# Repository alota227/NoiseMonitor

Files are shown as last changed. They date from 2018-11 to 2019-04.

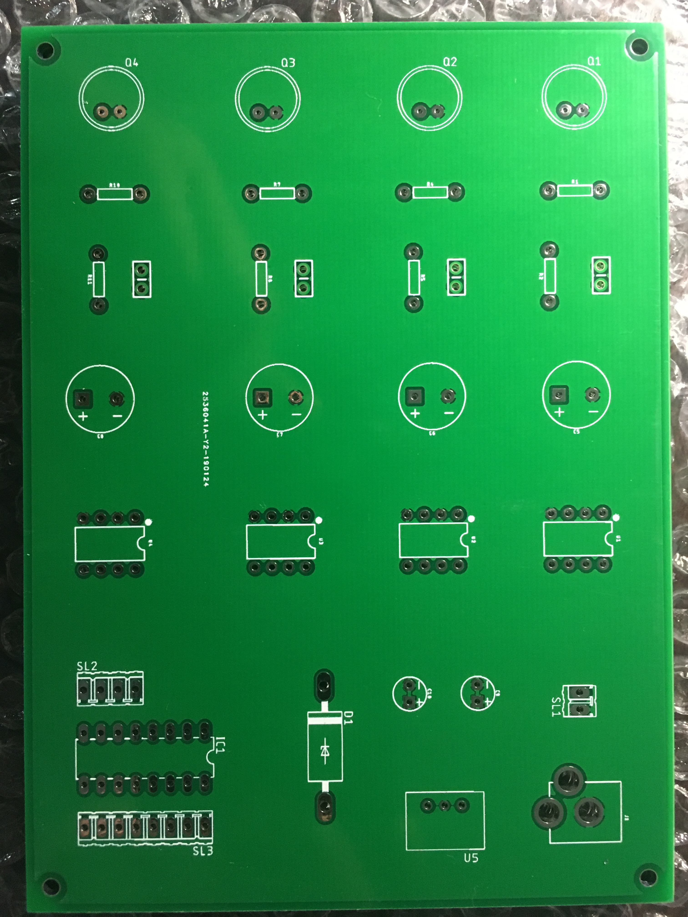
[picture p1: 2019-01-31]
PCB_Design_Eagle/IMG_4661.JPG

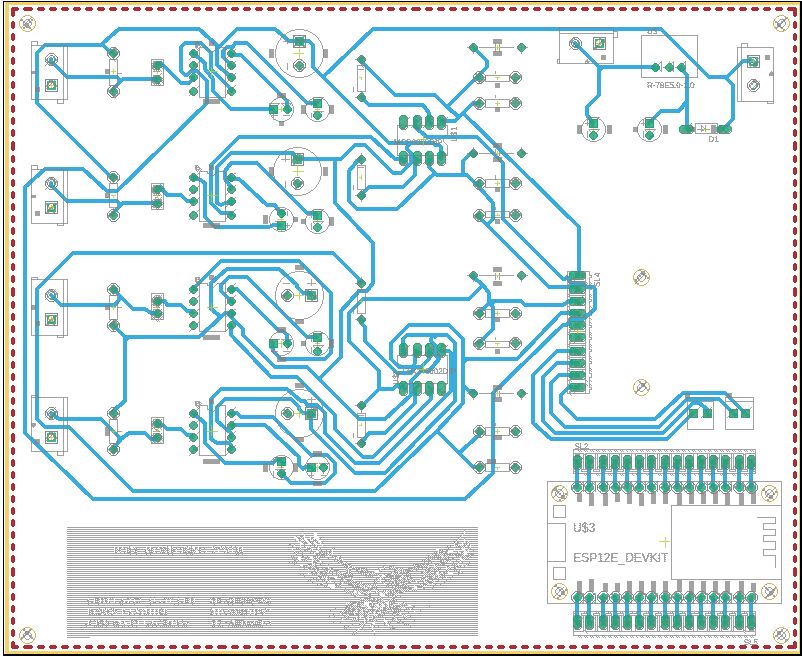
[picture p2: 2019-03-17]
PCB_Design_Eagle/Mic_PCB_Layout.JPG

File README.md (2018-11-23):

# NoiseMonitor
To design a  noise monitoring system that is able to detect and localize the noise levels in an area and analyze the data obtained through the cloud. The system will have several (2-3) nodes that can communicate with each other to analyze the data accurately. The data will be classified through an auto-map system that can identify the low/high level noise areas in real-time. The device is a solution that can solve the issues and concerns of noise pollution in Saskatchewan.

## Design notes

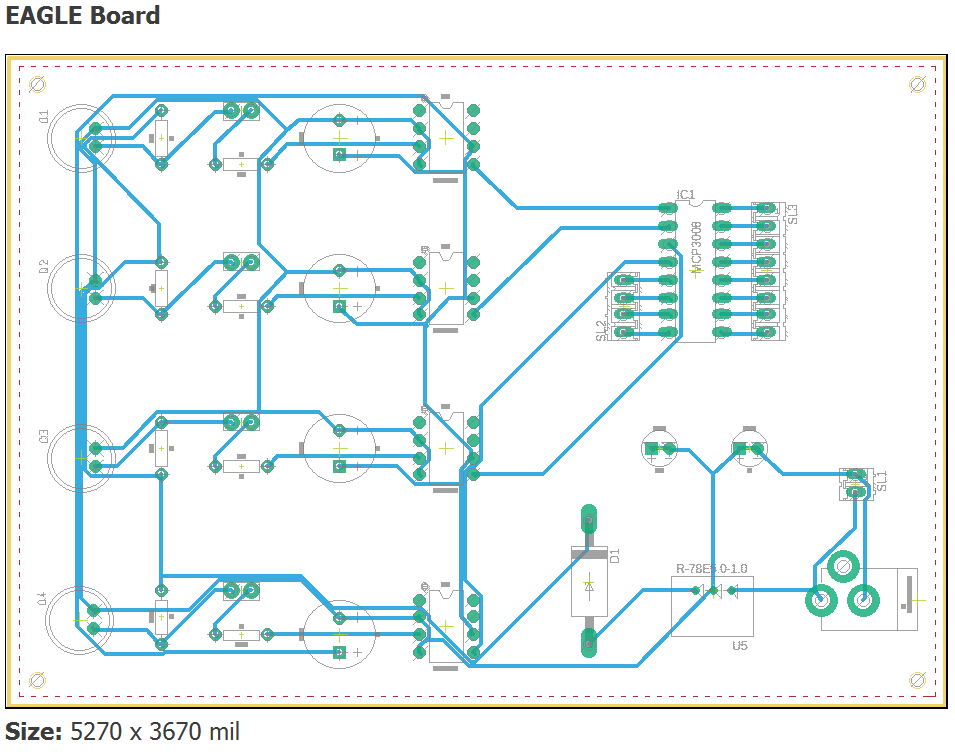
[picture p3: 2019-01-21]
PCB_Design_Eagle/node1_board_v2.PNG

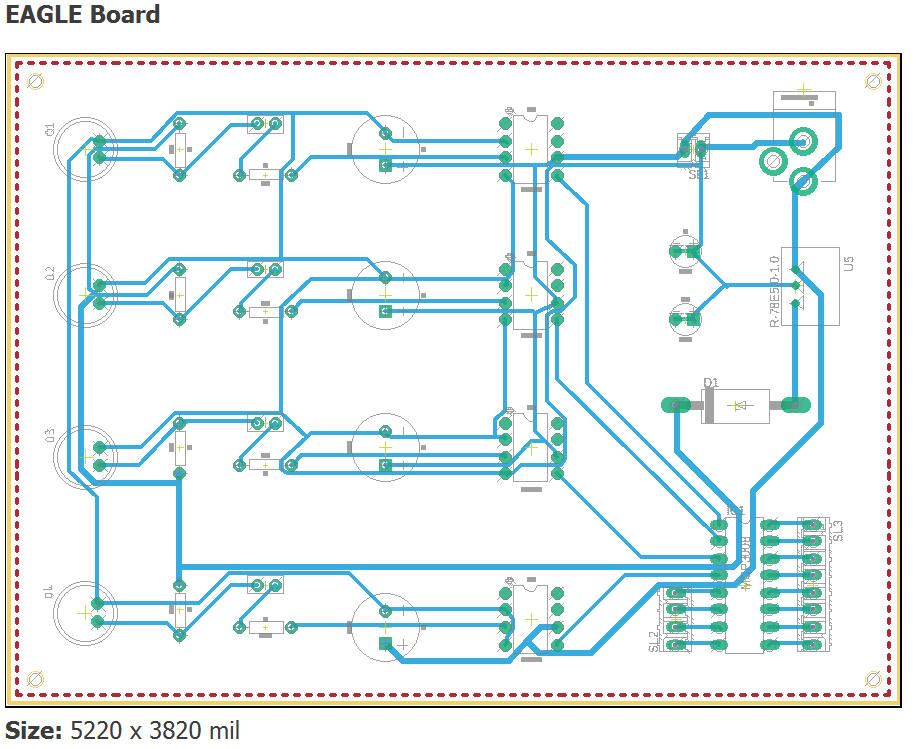
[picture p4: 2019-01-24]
PCB_Design_Eagle/node1_board_v33.PNG

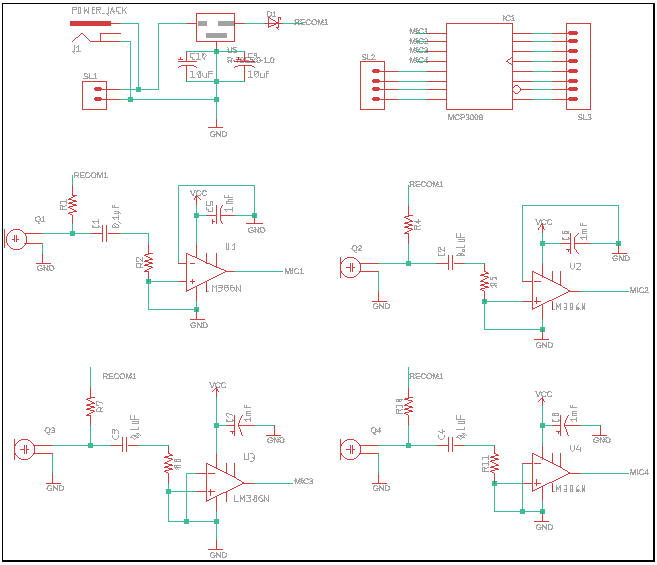
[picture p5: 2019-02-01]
PCB_Design_Eagle/Schematic.PNG

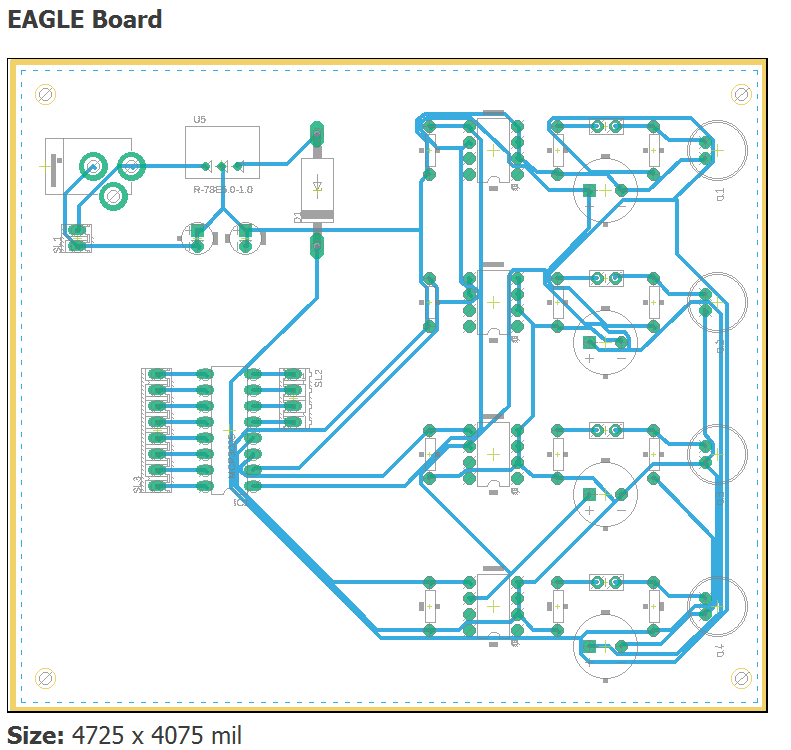
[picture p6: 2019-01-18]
PCB_Design_Eagle/node1_board_v1.PNG

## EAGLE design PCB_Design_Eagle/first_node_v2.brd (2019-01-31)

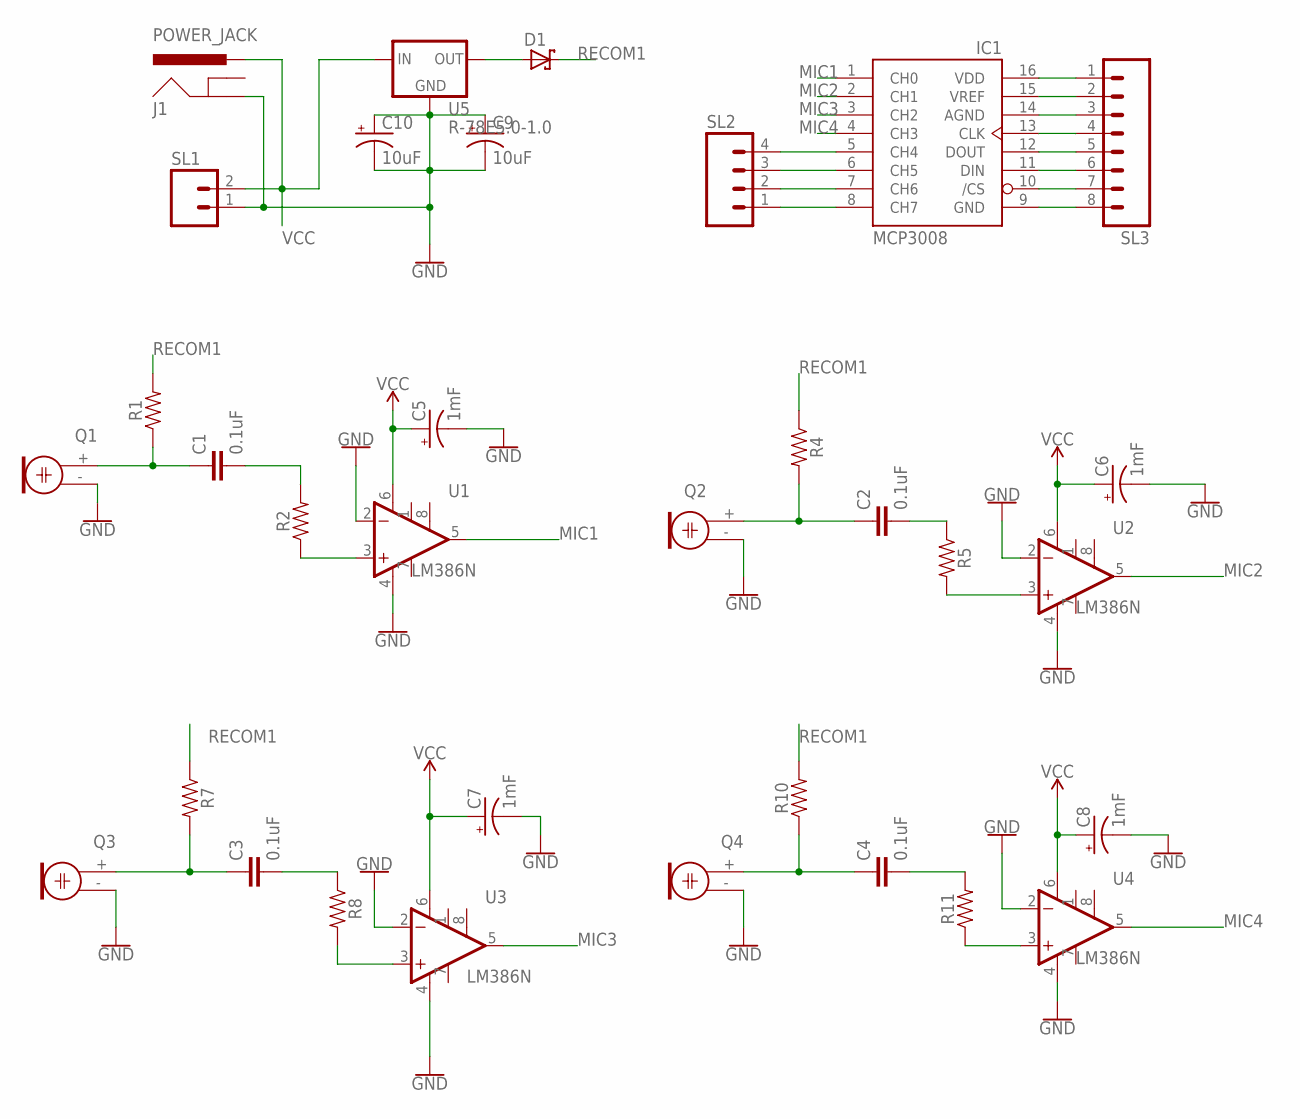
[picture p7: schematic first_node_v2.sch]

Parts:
C1, C2, C3, C4: 0.1uF; CAP-PTH-SMALL-KIT
C5, C6, C7, C8: 1mF; CPOL-RADIAL-5MM-10MM
C9, C10: 10uF; CPOL-RADIAL-2.5MM-5MM
D1: SCHOTTKY-DIODECB429-17; CB429-17
IC1: MCP3008; DIL16
J1: POWER_JACK; POWER_JACK_PTH
Q1, Q2, Q3, Q4: ELECTRET; 9.7ELECTRET
R1, R2, R4, R5, R7, R8, R10, R11: AXIAL-0.3
SL1: M02; 02P
SL2: M04; 04P
SL3: M08; 08P
U1, U2, U3, U4: LM386N; DIP08
U5: R-78E5.0-1.0; DC-DC_CONVERTER_78XX

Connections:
GND: C5.-, C6.-, C7.-, C8.-, C9.1 (+), C9.2 (-), C10.1 (+), C10.2 (-), J1.GND, Q1.- (1), Q2.- (1), Q3.- (1), Q4.- (1), SL1.1, U1.2 (-IN), U1.4 (V-), U2.2 (-IN), U2.4 (V-), U3.2 (-IN), U3.4 (V-), U4.2 (-IN), U4.4 (V-), U5.GND
MIC1: IC1.1 (CH0), U1.5 (OUT)
MIC2: IC1.2 (CH1), U2.5 (OUT)
MIC3: IC1.3 (CH2), U3.5 (OUT)
MIC4: IC1.4 (CH3), U4.5 (OUT)
unnamed: C1.1, Q1.+ (2), R1.P$1 (1)
unnamed: C1.2, R2.P$2 (2)
unnamed: C2.1, Q2.+ (2), R4.P$2 (2)
unnamed: C2.2, R5.P$1 (1)
unnamed: C3.1, Q3.+ (2), R7.P$2 (2)
unnamed: C4.1, Q4.+ (2), R10.P$1 (1)
unnamed: C3.2, R8.P$1 (1)
unnamed: C4.2, R11.P$2 (2)
unnamed: IC1.5 (CH4), SL2.4
unnamed: R8.P$2 (2), U3.3 (+IN)
unnamed: IC1.6 (CH5), SL2.3
unnamed: D1.A, U5.VOUT (OUT)
unnamed: IC1.7 (CH6), SL2.2
unnamed: IC1.8 (CH7), SL2.1
unnamed: IC1.16 (VDD), SL3.1
unnamed: IC1.15 (VREF), SL3.2
unnamed: IC1.14 (AGND), SL3.3
unnamed: IC1.13 (CLK), SL3.4
unnamed: IC1.12 (DOUT), SL3.5
unnamed: IC1.11 (DIN), SL3.6
unnamed: IC1.10 (/CS), SL3.7
unnamed: IC1.9 (GND), SL3.8
unnamed: R2.P$1 (1), U1.3 (+IN)
unnamed: R11.P$1 (1), U4.3 (+IN)
unnamed: R5.P$2 (2), U2.3 (+IN)
RECOM1: D1.C, R1.P$2 (2), R4.P$1 (1), R7.P$1 (1), R10.P$2 (2)
VCC: C5.+, C6.+, C7.+, C8.+, J1.PWR, SL1.2, U1.6 (V+), U2.6 (V+), U3.6 (V+), U4.6 (V+), U5.VIN (IN)

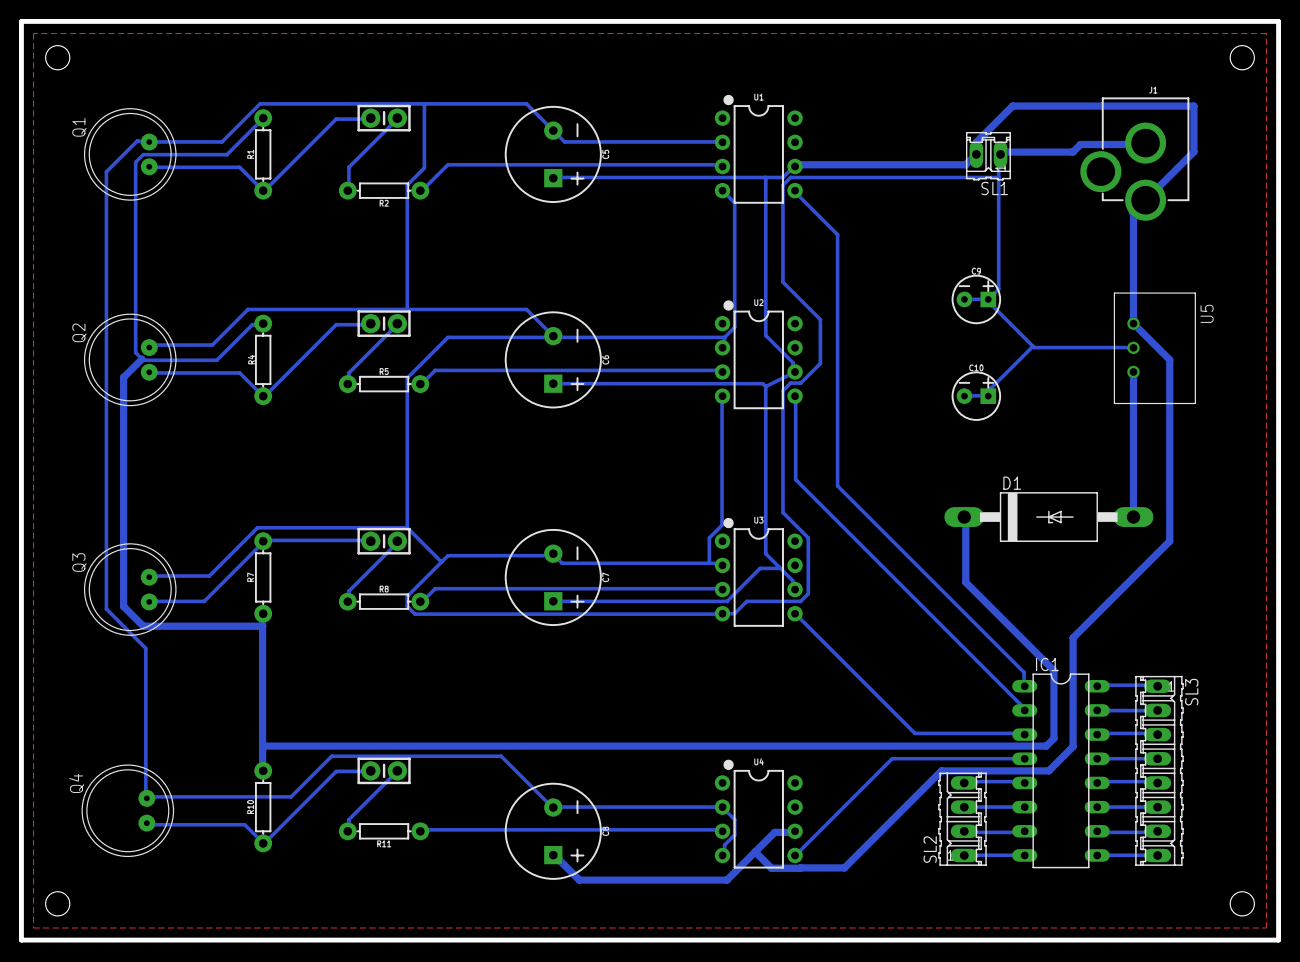
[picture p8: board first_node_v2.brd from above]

Board: 2 copper layers, 132.1 x 96.5 mm, 33 parts (0 on the bottom side), 32 nets.

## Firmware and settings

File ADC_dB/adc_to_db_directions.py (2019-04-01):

from machine import I2C, Pin, Timer
import ufirebase as firebase
import ads1x15
import time
from struct import unpack as unp
import network


addr = 72
gain = 1


i2c = I2C(scl=Pin(0), sda=Pin(4), freq=400000)
adc = ads1x15.ADS1015(i2c, addr, gain)

#
#URL = 'noise-c2b8e'
#print(firebase.get(URL))
#
def north_mic ():
    while True:
        result =adc.read(rate =7, channel1 =3) #Read ADC
        if (result < 893) and (result > 840): #Limiting ADC input to display 35-50
            result=(result-667.1349)/(4.33287) # Converting ADC to dB
            if (result < 52) and (result >38):  # Avoiding false data
                #result = np.float16(result)
                return result
        if (result <925) and (result > 892): #Limiting ADC input to display 50-60
            result=(result-747.2502)/(2.741792)# Converting ADC to dB
            if (result < 64) and (result >52):  # Avoiding false data
                #result = np.float16(result)
                return result            
        if (result <1020) and (result > 924): #Limiting ADC input to display 60-70
            result=(result-145.8678)/(18.3677)# Converting ADC to dB
            if (result < 71) and (result >61):  # Avoiding false data
                #result = np.float16(result)
                return result
        if (result <1200) and (result >1020): #Limiting ADC input to display 70-80
            result=(result+344.078)/(19.00119)# Converting ADC to dB
            if (result < 82) and (result >71):  # Avoiding false data
                #result = np.float16(result)
                return result
        if (result <1600) and (result >1199): #Limiting ADC input to display 80-90
            result=(result+1831.32)/(37.57249)# Converting ADC to dB
            if (result < 93) and (result >79):  # Avoiding false data
                #result = np.float16(result)
                return result
            
def east_mic ():
    while True:
        result =adc.read(rate =7, channel1 =2) #Read ADC
        if (result < 893) and (result > 840): #Limiting ADC input to display 35-50
            result=(result-667.1349)/(4.33287) # Converting ADC to dB
            if (result < 52) and (result >38):  # Avoiding false data
                #result = np.float16(result)
                return result
        if (result <925) and (result > 892): #Limiting ADC input to display 50-60
            result=(result-747.2502)/(2.741792)# Converting ADC to dB
            if (result < 64) and (result >52):  # Avoiding false data
                #result = np.float16(result)
                return result            
        if (result <1020) and (result > 924): #Limiting ADC input to display 60-70
            result=(result-145.8678)/(18.3677)# Converting ADC to dB
            if (result < 71) and (result >61):  # Avoiding false data
                #result = np.float16(result)
                return result
        if (result <1200) and (result >1020): #Limiting ADC input to display 70-80
            result=(result+344.078)/(19.00119)# Converting ADC to dB
            if (result < 82) and (result >71):  # Avoiding false data
                #result = np.float16(result)
                return result
        if (result <1600) and (result >1199): #Limiting ADC input to display 80-90
            result=(result+1831.32)/(37.57249)# Converting ADC to dB
            if (result < 93) and (result >79):  # Avoiding false data
                #result = np.float16(result)
                return result           
 
def south_mic ():
    while True:
        result =adc.read(rate =7, channel1 =1) #Read ADC
        if (result < 893) and (result > 840): #Limiting ADC input to display 35-50
            result=(result-667.1349)/(4.33287) # Converting ADC to dB
            if (result < 52) and (result >38):  # Avoiding false data
                #result = np.float16(result)
                return result
        if (result <925) and (result > 892): #Limiting ADC input to display 50-60
            result=(result-747.2502)/(2.741792)# Converting ADC to dB
            if (result < 64) and (result >52):  # Avoiding false data
                #result = np.float16(result)
                return result            
        if (result <1020) and (result > 924): #Limiting ADC input to display 60-70
            result=(result-145.8678)/(18.3677)# Converting ADC to dB
            if (result < 71) and (result >61):  # Avoiding false data
                #result = np.float16(result)
                return result
        if (result <1200) and (result >1020): #Limiting ADC input to display 70-80
            result=(result+344.078)/(19.00119)# Converting ADC to dB
            if (result < 82) and (result >71):  # Avoiding false data
                #result = np.float16(result)
                return result
        if (result <1600) and (result >1199): #Limiting ADC input to display 80-90
            result=(result+1831.32)/(37.57249)# Converting ADC to dB
            if (result < 93) and (result >79):  # Avoiding false data
                #result = np.float16(result)
                return result

def west_mic ():
    while True:
        result =adc.read(rate =7, channel1 =0) #Read ADC
        if (result < 893) and (result > 840): #Limiting ADC input to display 35-50
            result=(result-667.1349)/(4.33287) # Converting ADC to dB
            if (result < 52) and (result >38):  # Avoiding false data
                #result = np.float16(result)
                return result
        if (result <925) and (result > 892): #Limiting ADC input to display 50-60
            result=(result-747.2502)/(2.741792)# Converting ADC to dB
            if (result < 64) and (result >52):  # Avoiding false data
                #result = np.float16(result)
                return result            
        if (result <1020) and (result > 924): #Limiting ADC input to display 60-70
            result=(result-145.8678)/(18.3677)# Converting ADC to dB
            if (result < 71) and (result >61):  # Avoiding false data
                #result = np.float16(result)
                return result
        if (result <1200) and (result >1020): #Limiting ADC input to display 70-80
            result=(result+344.078)/(19.00119)# Converting ADC to dB
            if (result < 82) and (result >71):  # Avoiding false data
                #result = np.float16(result)
                return result
        if (result <1600) and (result >1199): #Limiting ADC input to display 80-90
            result=(result+1831.32)/(37.57249)# Converting ADC to dB
            if (result < 93) and (result >79):  # Avoiding false data
                #result = np.float16(result)
                return result
            
def direction (): #compares the dB levels of each microphone and deterimine the direction of the sound
    north1=north_mic()
    east1=east_mic()
    south1=south_mic()
    west1=west_mic()
    
    addNE= (north1 + east1)
    addNW= (north1 + west1)
    addSE= (south1 + east1)
    addSW= (south1 + west1)
    subNE= (north1 - east1)
    subNW= (north1 - west1)
    subSE= (south1 - east1)
    subSW= (south1 - west1)    
    
    ## Checks for N, NE, NW
    if (north1>east1 and north1>south1 and north1>west1): ## checks if north is largest reading
        if ((addNE > addNW) and (addNE > addSW) and (addNE > addSE ) and (subNE > -6 and subNE < 6)):
            print ("North East")
        elif ((addNW > addNE) and (addNW > addSW) and (addNW > addSE) and (subNW > -6 and subNW < 6)):
            print ("North West")
        else:
            print ("North")
            
     ## Checks for S, SE, SW
    if (south1>east1 and south1>north1 and south1>west1): ## checks if south is largest reading
        if ((addSE > addNW) and (addSE > addNE) and (addSE > addSW) and (subSE > -6 and subSE < 6)):
            print ("South East")
        elif ((addSW > addNE) and (addSW > addNW) and (addSW > addSE) and (subSW > -6 and subSW < 6)):
            print ("South West")
        else:
            print ("South")
            
     ## Checks for E, NE, SE
    if (east1>south1 and east1>north1 and east1>west1): ## checks if east is largest reading
        if ((addSE > addNW) and (addSE > addSW) and (addSE > addNE) and (subSE > -6 and subSE < 6)):
            print ("South East")
        elif ((addNE > addNW) and (addNE > addSW) and (addNE > addSE) and (subNE > -6 and subNE < 6)):
            print ("North East")
        else:
            print ("East")

     ## Checks for W, NW, SW
    if (west1>south1 and west1>north1 and west1>east1): ## checks if west is largest reading
        if ((addSW > addNW) and (addSW > addSE) and (addSW > addNE) and (subSW > -6 and subSW < 6)):
            print ("South West")
        elif ((addNW > addNE) and (addNW > addSW) and (addNW > addSE) and (subNW > -6 and subNW < 6) ): 
            print ("North West")
        else:
            print ("West")

            
            
#URL = 'noise-c2b8e'
#print(firebase.get(URL))
while True:

        
    result= south_mic()
    result2= north_mic()
    result3= west_mic()
    result4 = east_mic()
        #firebase.put(URL,{'West':result, 'South':resultS})
        #firebase.put(URL,{'South':resultS})
        #firebase.put(URL,{'West':result})
    print (result)
    print(result2)
    print(result3)
    print(result4)
    dir= direction()


        #print("-------------------")
        #firebase.put(URL, {'Mic1': Mic1_Val})
    time.sleep(0.5)


    #value = adc.read(rate =7, channel1 =0)
#    value = adc.read(rate =7, channel1 =1)
    #value = adc.read(rate =7, channel1 =2)
    #rv = 
#    result= conv_to_db()
#    #print(conv_to_db())
#    firebase.put(URL,{'North':result})
#    print (value)
#    #firebase.put(URL, {'Mic1': Mic1_Val})
#    time.sleep(0.1)

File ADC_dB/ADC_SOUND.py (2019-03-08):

# Simple demo of reading each analog input from the ADS1x15 and printing it to
# the screen.
# Author: Tony DiCola
# Edited by: Abdulaziz Alotaibi / University of Regina 2019
# License: Public Domain
import time
import numpy as np
import Adafruit_ADS1x15
import csv
import math

# Create an ADS1115 ADC (16-bit) instance.
#adc = Adafruit_ADS1x15.ADS1115()

# Or create an ADS1015 ADC (12-bit) instance.
adc = Adafruit_ADS1x15.ADS1015()

# Note you can change the I2C address from its default (0x48), and/or the I2C
# bus by passing in these optional parameters:
#adc = Adafruit_ADS1x15.ADS1015(address=0x49, busnum=1)

# Choose a gain of 1 for reading voltages from 0 to 4.09V.# Or pick a different gain to change the range of voltages that are read:
#  - 2/3 = +/-6.144V
#  -   1 = +/-4.096V
#  -   2 = +/-2.048V
#  -   4 = +/-1.024V
#  -   8 = +/-0.512V
#  -  16 = +/-0.256V
GAIN = 1

print('Reading ADS1x15 values, press Ctrl-C to quit...')
#with open("dB_Values22.cvs", "w") as out_file

def conv_db_quad ():
    while True:
        result =adc.read_adc(0, gain=GAIN, data_rate=3300)
        #if (result < 1350) and (result > 1100):

def db_quad():
    while True:
        result =adc.read_adc(0, gain=GAIN, data_rate=3300)
        if (result<2500) and (result > 1332.2):
            result = (27.0558+(math.sqrt(1.09702*result-1461.25797)))/(0.54851)
            if (result < 100) and (result > 35):
                return result
def conv_db ():
    while True:
        result =adc.read_adc(0, gain=GAIN, data_rate=3300) #Read ADC
        if (result < 1363) and (result > 1230): #Limiting ADC input to display 35-50
            result=(result-990.8196)/(6.163967) # Converting ADC to dB
            if (result < 62) and (result >35):  # Avoiding false data
                return result
        if (result <1500) and (result > 1390): #Limiting ADC input to display 35-50
            result=(result-150.0336)/(19.1704)# Converting ADC to dB
            if (result < 72) and (result >61):  # Avoiding false data
                return result            
        if (result <1621) and (result > 1520): #Limiting ADC input to display 35-50
            result=(result-145.8678)/(18.3677)# Converting ADC to dB
            if (result < 82) and (result >71):  # Avoiding false data
                return result
        if (result <1940) and (result >1621): #Limiting ADC input to display 35-50
            result=(result+902.623)/(31.10444)# Converting ADC to dB
            if (result < 99) and (result >81):  # Avoiding false data
                return result
##dataset=open("dataset55555.csv", "w")
##def write_data():
##    obj=csv.writer(dataset)
##    obj.writerow([db_value()])
##
##while True:
##    write_data()
##dataset.close()

while True:
    
    #res =db_value()
    #read_adc_ch0 =adc.read_adc(0, gain=GAIN,data_rate=3300)
    print conv_db()
    #print db_value()
    #print read_adc_ch0
    time.sleep(0.5)

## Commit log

2019-01-18 Add files via upload
    Initial PCB design of an individual node
    [circuitDiagram.sch]
2019-01-31 Create PCB_Design
2019-01-31 Add files via upload
    gerber file

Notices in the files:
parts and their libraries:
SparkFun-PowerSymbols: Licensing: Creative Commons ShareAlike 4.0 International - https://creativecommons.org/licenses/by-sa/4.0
